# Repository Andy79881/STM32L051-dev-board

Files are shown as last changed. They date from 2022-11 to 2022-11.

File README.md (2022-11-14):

# STM32L051-dev-board
### ***A small-footprint, custom development PCB for the STM32L051C8Tx***

* This board's MCU is an Access line ultra low power STM32L051C8T6 with 64 kB of flash, 8 kB of SRAM and an ARM Cortex-M0+ core in a 48-pin LQFP package.

* The board supports I<sup>2</sup>C, SPI and UART as communication interfaces. Checkout the datasheet for details.
* Flashing and In-Circuit-Debugging can be achieved through an ST-LINK V3 Mini external flasher / debugger using the SWD protocol. The development board provides an 14 pin connector with 1.27mm pitch (J1) for direct connection to the ST-Link V3 Mini via STDC14 flat
cable. USART2 is available on connector J1 as well. Alternatively, any other suitable programmer can be connected via P1 and jumper wires.
* The board is powered via VPP (+5V) and draws very little current. Power conversion occurs through an onboard 5~3.3V linear regulator.
* The board has a 32.768 kHz clock for RTC capabilities as well as an 8.000 MHz system clock. It also features an indicator LED together with an open collector stage to drive higher current load (both assigned at PC13), a reset button and a boot select jumper.
* The footprint of the board is 32x54 mm and its 2.54 mm pitch headers allow it to be used with standard breadboards.

---

**I/O connectors (J2, J4) Pinout 1)**

<table>
<tr>
<th>J2</th>
<th>J4</th>
</tr>
<tr>

<td>

| Pin no | Pin name  |
|---|---|
| 1 | GND |
| 2 | Load 2) |
| 3 | PA0 |
| 4 | PA1 |
| 5 | PA4 |
| 6 | PA5 |
| 7 | PA6 |
| 8 | PA7 |
| 9 | PB0 |
| 10 | PB1 |
| 11 | PB2 |
| 12 | PB10 |
| 13 | PB11 |
| 14 | PB12 |
| 15 | PB13 |
| 16 | PB14 |

</td><td>

| Pin no | Pin name  |
|---|---|
| 1 | PB9 |
| 2 | PB8 |
| 3 | PB7 |
| 4 | PB6 |
| 5 | PB5 |
| 6 | PB4 |
| 7 | PB3 |
| 8 | PA15 |
| 9 | PA12 |
| 10 | PA11 |
| 11 | PA10 |
| 12 | PA9 |
| 13 | PA8 |
| 14 | PB15 |
| 15 | GND |
| 16 | VPP (+5V) |

</td></tr> </table>

**Notes:**
1. J2 left, J4 right for PCB front view
2. PC13 assigned to open collector output and built-in LED 

| Front view | Rear view |
|---|---|
|grafik |grafik |

SWD debug / programming connector for ST-link V3 mini highlighted.

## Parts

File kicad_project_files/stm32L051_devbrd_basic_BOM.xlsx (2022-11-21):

Id | Designator | Package | Quantity | Designation | Supplier and ref
1 | P1 | PinHeader_1x05_P2.54mm_Horizontal | 1 | CONN5
2 | D2 | LED_0805_2012Metric_Pad1.15x1.40mm_HandSolder | 1 | LED yellow
3 | TP4,TP3,TP2,TP1 | TestPoint_Pad_D1.0mm | 4 | TestPoint
4 | J1 | PinHeader_2x07_P1.27mm_Vertical | 1 | Conn_02x07_Odd_Even
5 | J3 | PinHeader_2x02_P2.54mm_Vertical | 1 | Conn_02x02_Odd_Even
6 | TP5,TP6 | TestPoint_Keystone_5000-5004_Miniature | 2 | TestPoint
7 | R3,R6,R2 | R_0805_2012Metric_Pad1.20x1.40mm_HandSolder | 3 | 10k
8 | Y1 | Crystal_SMD_HC49-SD | 1 | 8.000 MHz
9 | U2 | LQFP-48_7x7mm_P0.5mm | 1 | STM32L051C8Tx_new
10 | SW1 | SW_SPST_B3S-1000 | 1 | SW_Push
11 | C10,C11 | C_0603_1608Metric | 2 | 20p
12 | C7 | CP_Elec_4x5.8 | 1 | 2.2u
13 | R7 | R_0805_2012Metric_Pad1.20x1.40mm_HandSolder | 1 | 100k
14 | R5 | R_0805_2012Metric_Pad1.20x1.40mm_HandSolder | 1 | 3k3
15 | C1 | C_1210_3225Metric_Pad1.33x2.70mm_HandSolder | 1 | 4.7u
16 | Q1 | SOT-23 | 1 | BC817
17 | C3,C9,C6,C5,C8,C4 | C_0805_2012Metric_Pad1.18x1.45mm_HandSolder | 6 | 100n
18 | Y2 | Crystal_SMD_3215-2Pin_3.2x1.5mm | 1 | 32.768kHz
19 | J2 | PinHeader_1x16_P2.54mm_Vertical | 1 | Conn_01x16
20 | R4 | R_0805_2012Metric_Pad1.20x1.40mm_HandSolder | 1 | 390
21 | C2 | C_0805_2012Metric_Pad1.18x1.45mm_HandSolder | 1 | 1u
22 | R1 | R_0805_2012Metric_Pad1.20x1.40mm_HandSolder | 1 | 22
23 | J4 | PinHeader_1x16_P2.54mm_Vertical | 1 | Conn_01x18
24 | U1 | SOT-223-3_TabPin2 | 1 | MCP1755S-3302E/DB
25 | FB1 | L_0805_2012Metric_Pad1.05x1.20mm_HandSolder | 1 | 600R/0.7A
26 | C13,C12 | C_0603_1608Metric | 2 | 10p
27 | D1 | D_SOD-123 | 1 | MBR0540

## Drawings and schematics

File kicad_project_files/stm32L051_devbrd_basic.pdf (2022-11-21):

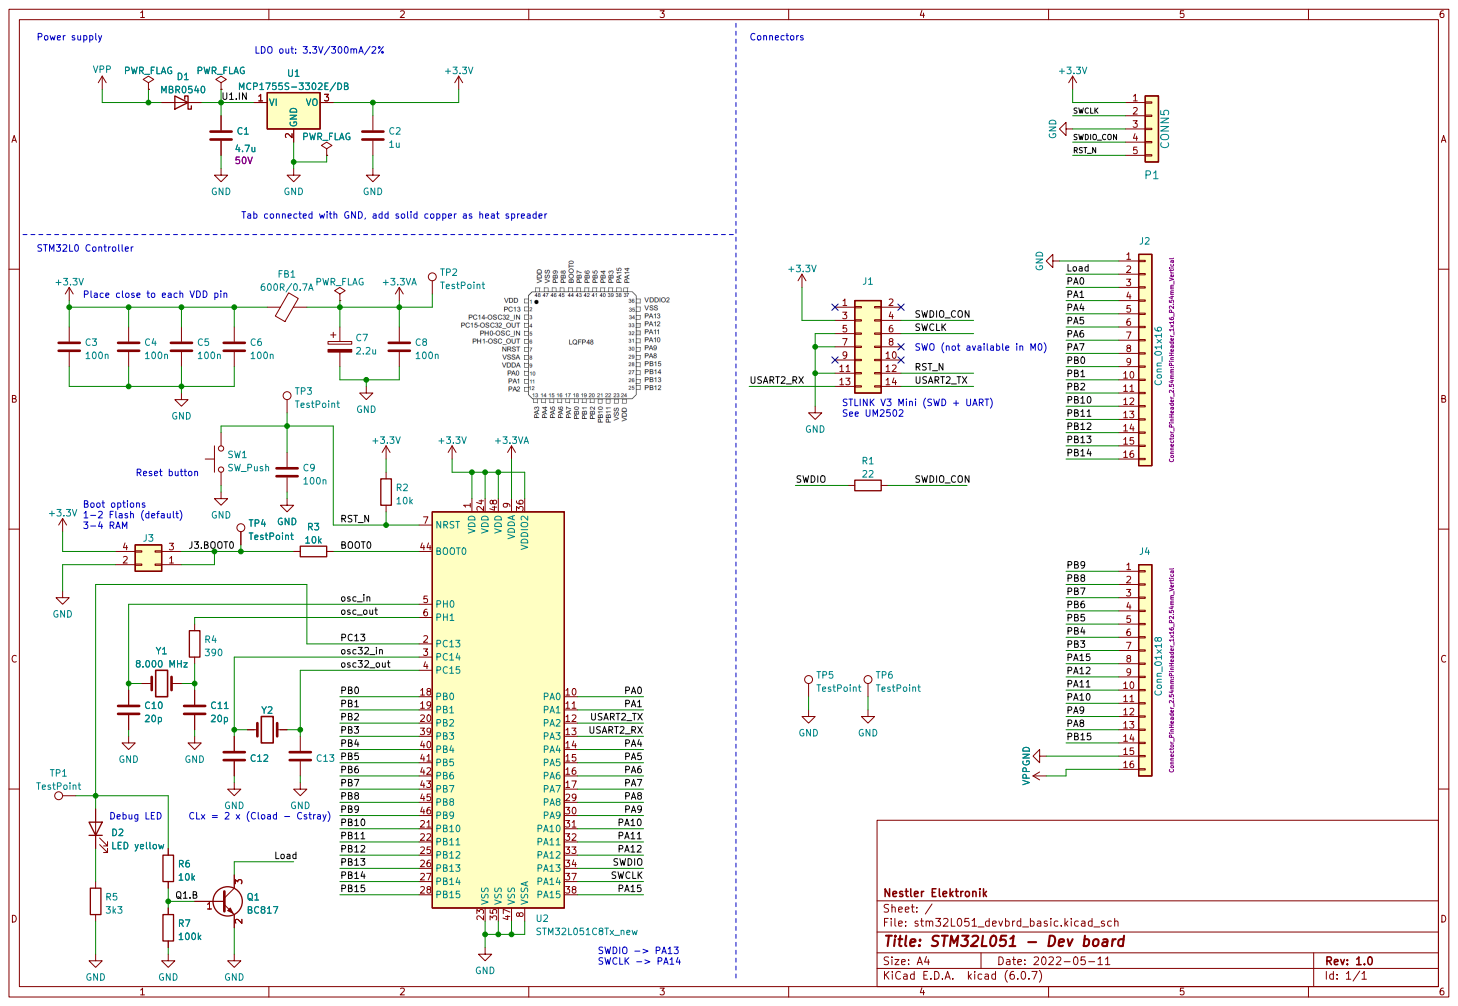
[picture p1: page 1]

File: stm32L051_devbrd_basic.kicad_sch Sheet: / Nestler Elektronik GND

Id: 1/1 Title: STM32L051 - Dev board

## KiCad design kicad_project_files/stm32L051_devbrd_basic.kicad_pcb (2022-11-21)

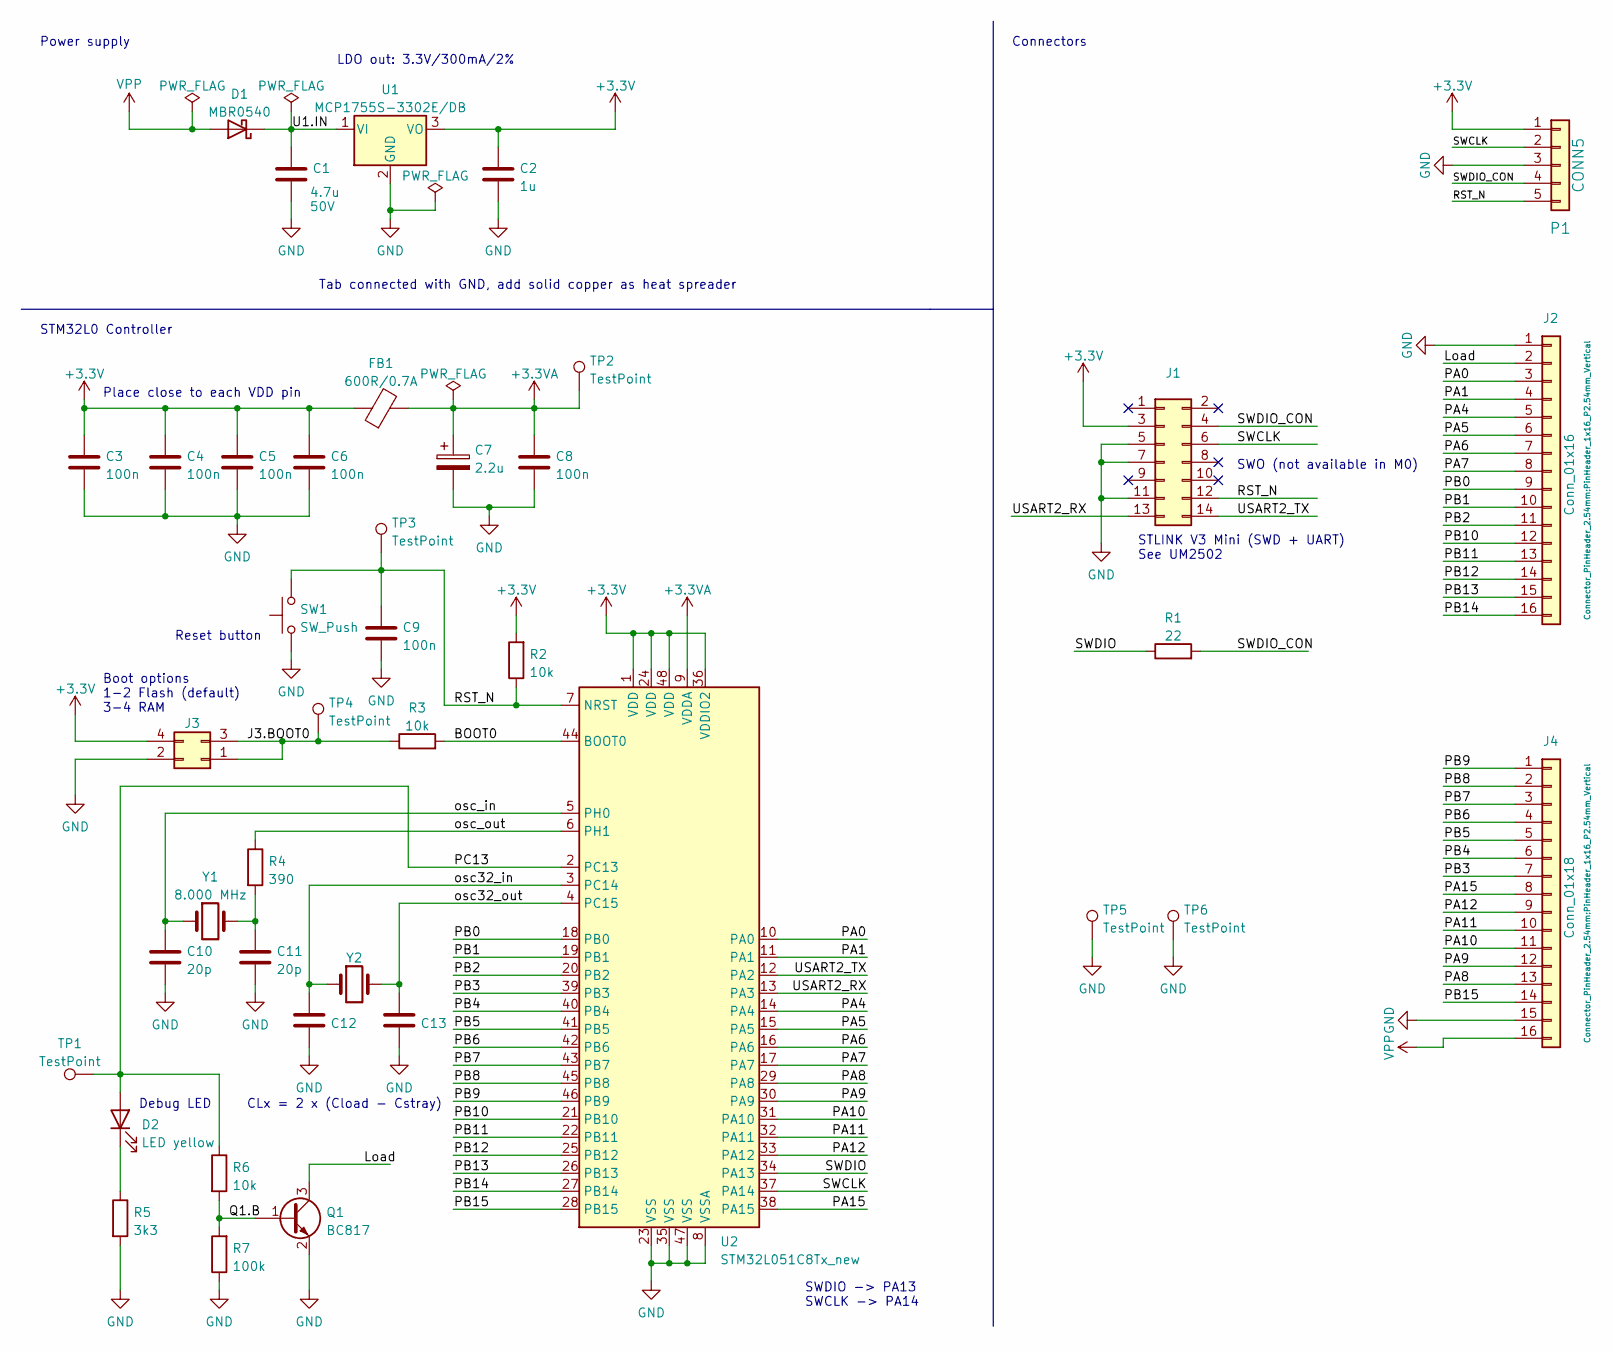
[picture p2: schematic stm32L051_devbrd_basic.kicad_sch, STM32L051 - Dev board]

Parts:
C1: 4.7u; C_1210_3225Metric_Pad1.33x2.70mm_HandSolder
C2: 1u; C_0805_2012Metric_Pad1.18x1.45mm_HandSolder
C3, C4, C5, C6, C8, C9: 100n; C_0805_2012Metric_Pad1.18x1.45mm_HandSolder
C7: 2.2u; CP_Elec_4x5.8
C10, C11: 20p; C_0603_1608Metric
C12, C13: 10p; C_0603_1608Metric
D1: MBR0540; D_SOD-123
D2: LED yellow; LED_0805_2012Metric_Pad1.15x1.40mm_HandSolder
FB1: 600R/0.7A; L_0805_2012Metric_Pad1.05x1.20mm_HandSolder
J1: Conn_02x07_Odd_Even; PinHeader_2x07_P1.27mm_Vertical
J2: Conn_01x16; PinHeader_1x16_P2.54mm_Vertical
J3: Conn_02x02_Odd_Even; PinHeader_2x02_P2.54mm_Vertical
J4: Conn_01x18; PinHeader_1x16_P2.54mm_Vertical
P1: CONN5; PinHeader_1x05_P2.54mm_Horizontal
Q1: BC817; SOT-23
R1: 22; R_0805_2012Metric_Pad1.20x1.40mm_HandSolder
R2, R3, R6: 10k; R_0805_2012Metric_Pad1.20x1.40mm_HandSolder
R4: 390; R_0805_2012Metric_Pad1.20x1.40mm_HandSolder
R5: 3k3; R_0805_2012Metric_Pad1.20x1.40mm_HandSolder
R7: 100k; R_0805_2012Metric_Pad1.20x1.40mm_HandSolder
SW1: SW_Push; SW_SPST_B3S-1000
TP1, TP2, TP3, TP4: TestPoint; TestPoint_Pad_D1.0mm
TP5, TP6: TestPoint; TestPoint_Keystone_5000-5004_Miniature
U1: MCP1755S-3302E/DB; SOT-223-3_TabPin2
U2: STM32L051C8Tx_new; LQFP-48_7x7mm_P0.5mm
Y1: 8.000 MHz; Crystal_SMD_HC49-SD
Y2: 32.768kHz; Crystal_SMD_3215-2Pin_3.2x1.5mm

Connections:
+3.3V: C2.1, C3.1, C4.1, C5.1, C6.1, FB1.1, J1.3, J3.4, P1.1, R2.2, U1.3 (VO), U2.1 (VDD), U2.24 (VDD), U2.36 (VDDIO2), U2.48 (VDD)
+3.3VA: C7.1, C8.1, FB1.2, TP2.1, U2.9 (VDDA)
/BOOT0: R3.2, U2.44 (BOOT0)
/J3.BOOT0: J3.1, J3.3, R3.1, TP4.1
/Load: J2.2, Q1.3 (C)
/PA0: J2.3, U2.10 (PA0)
/PA1: J2.4, U2.11 (PA1)
/PA4: J2.5, U2.14 (PA4)
/PA5: J2.6, U2.15 (PA5)
/PA6: J2.7, U2.16 (PA6)
/PA7: J2.8, U2.17 (PA7)
/PA8: J4.13, U2.29 (PA8)
/PA9: J4.12, U2.30 (PA9)
/PA10: J4.11, U2.31 (PA10)
/PA11: J4.10, U2.32 (PA11)
/PA12: J4.9, U2.33 (PA12)
/PA15: J4.8, U2.38 (PA15)
/PB0: J2.9, U2.18 (PB0)
/PB1: J2.10, U2.19 (PB1)
/PB2: J2.11, U2.20 (PB2)
/PB3: J4.7, U2.39 (PB3)
/PB4: J4.6, U2.40 (PB4)
/PB5: J4.5, U2.41 (PB5)
/PB6: J4.4, U2.42 (PB6)
/PB7: J4.3, U2.43 (PB7)
/PB8: J4.2, U2.45 (PB8)
/PB9: J4.1, U2.46 (PB9)
/PB10: J2.12, U2.21 (PB10)
/PB11: J2.13, U2.22 (PB11)
/PB12: J2.14, U2.25 (PB12)
/PB13: J2.15, U2.26 (PB13)
/PB14: J2.16, U2.27 (PB14)
/PB15: J4.14, U2.28 (PB15)
/PC13: D2.2 (A), R6.1, TP1.1, U2.2 (PC13)
/Q1.B: Q1.1 (B), R6.2, R7.2
/RST_N: C9.1, J1.12, P1.5, R2.1, SW1.2, TP3.1, U2.7 (NRST)
/SWCLK: J1.6, P1.2, U2.37 (PA14)
/SWDIO: R1.1, U2.34 (PA13)
/SWDIO_CON: J1.4, P1.4, R1.2
/U1.IN: C1.1, D1.1 (K), U1.1 (VI)
/USART2_RX: J1.13, U2.13 (PA3)
/USART2_TX: J1.14, U2.12 (PA2)
/osc32_in: C12.1, U2.3 (PC14), Y2.1
/osc32_out: C13.1, U2.4 (PC15), Y2.2
/osc_in: C10.1, U2.5 (PH0), Y1.1
/osc_out: R4.1, U2.6 (PH1)
GND: C1.2, C2.2, C3.2, C4.2, C5.2, C6.2, C7.2, C8.2, C9.2, C10.2, C11.2, C12.2, C13.2, J1.5, J1.7, J1.11, J2.1, J3.2, J4.15, P1.3, Q1.2 (E), R5.2, R7.1, SW1.1, TP5.1, TP6.1, U1.2 (GND), U2.8 (VSSA), U2.23 (VSS), U2.35 (VSS), U2.47 (VSS)
unnamed: C11.1, R4.2, Y1.2
unnamed: D2.1 (K), R5.1
VPP: D1.2 (A), J4.16

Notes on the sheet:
CLx = 2 x (Cload - Cstray)
Boot options 1-2 Flash (default) 3-4 RAM
Tab connected with GND, add solid copper as heat spreader
Place close to each VDD pin
STLINK V3 Mini (SWD + UART) See UM2502
SWDIO -> PA13 SWCLK -> PA14
Connectors
LDO out: 3.3V/300mA/2%
Debug LED
Power supply
SWO (not available in M0)
Reset button
STM32L0 Controller

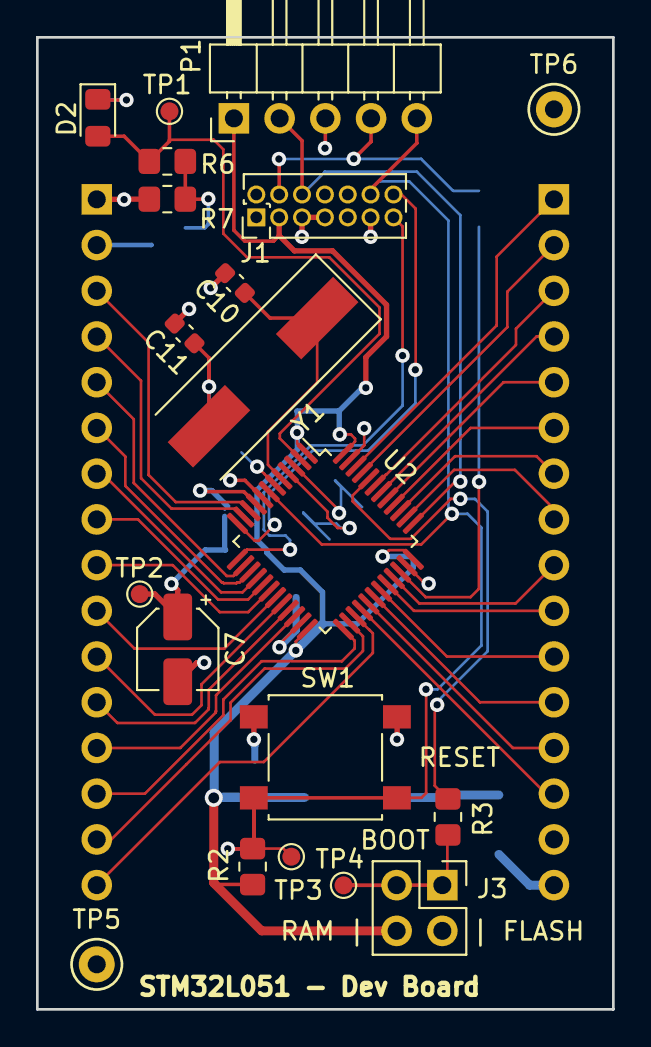
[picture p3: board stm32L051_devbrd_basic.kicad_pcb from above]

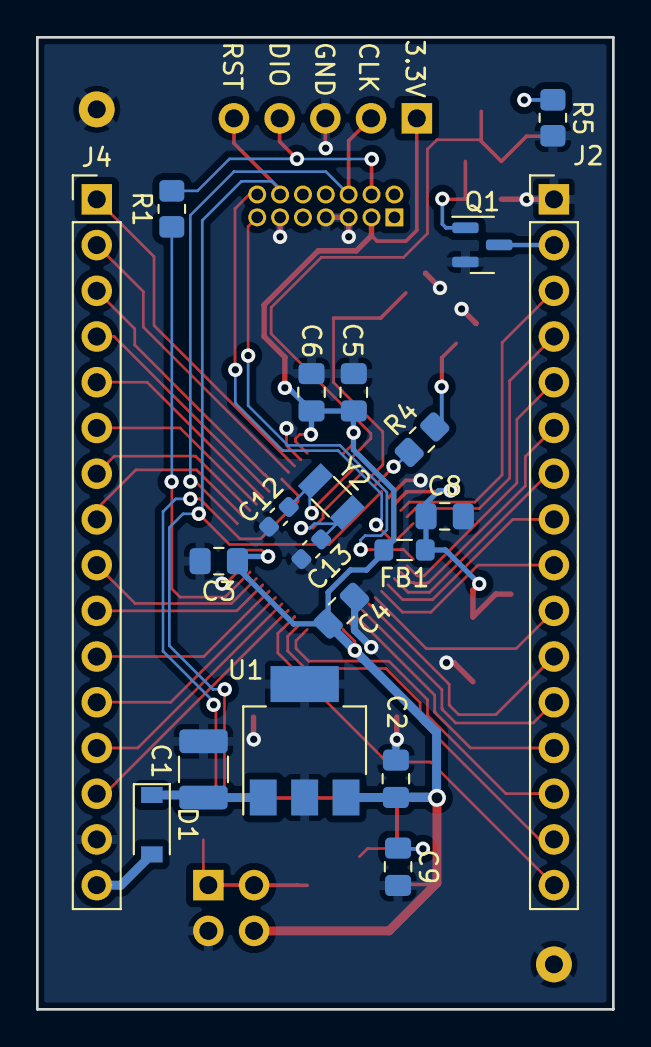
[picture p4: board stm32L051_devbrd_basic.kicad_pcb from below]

Board: 2 copper layers, 32.0 x 54.0 mm, 40 parts (20 on the bottom side), 50 nets.

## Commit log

2022-11-14 Update README.md
    IO connector tables for J2, J4 side by side. Refer to https://towardsdatascience.com/the-ultimate-markdown-cheat-sheet-3d3976b31a0
2022-11-21 Add files via upload
    Initial file upload of Kicad project
    [stm32L051_devbrd_basic.kicad_pcb, stm32L051_devbrd_basic.kicad_sch, stm32L051_devbrd_basic_BOM.xlsx]
